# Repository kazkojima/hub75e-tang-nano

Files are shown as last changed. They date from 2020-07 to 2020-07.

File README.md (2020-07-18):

## HUB75E driver with Tang Nano FPGA and WiFi adaptor with M5ATOM

The driver part by Tang Nano for 64x64 LED panels with the HUB75E
interface is based on https://github.com/shinyblink/sled-fpga-hub75.

The WiFi part by M5ATOM is an esp-idf application. It receives RGB565
udp packet format of [LED master](https://github.com/spectrenoir06/LED_master)
and writes the frame data to FPGA with SPI.

The main SPI should assert CS, write 64x64(4096) RGB555 words and negate CS
with mode0. The HUB75E panel is divided to 2 64x32 planes and the SPI data
should be organized as

```
   word 0, word 2048, word 1, word 2049, ... , word 2047, word 4095
```

so as to get 2 words for both panels at the same time with one 32-bit data
from BRAM.

This driver does nothing to sync frame read/write from/to BRAM, the images
displayed on the top and bottom panels may be out of sync.

I use 16Mhz clock for the base clock to minimize the artifacts on my panel,
though there may be panels which can be ok with the higher clocks. SPI
requires the base clock which is at least x4 the SCLK, i.e. the maximal
SCLK is limited by 4Mhz for the 16Mhz base clock.

All sources are covered by ISC License, except src/hub75e.{sdc,cst} files
which are generated files by GOWIN IDE.

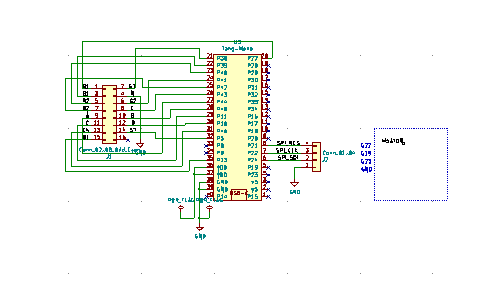
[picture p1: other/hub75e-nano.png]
simple schematic


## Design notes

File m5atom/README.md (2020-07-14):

## M5ATOM Matrix ESP-IDF sample

This is a sample application of M5ATOM Matrix. Recieve RGB565 format udp
packets from [LEDs master](https://github.com/spectrenoir06/LED_master)
amd writes the frame to HUB75E interface via SPI.

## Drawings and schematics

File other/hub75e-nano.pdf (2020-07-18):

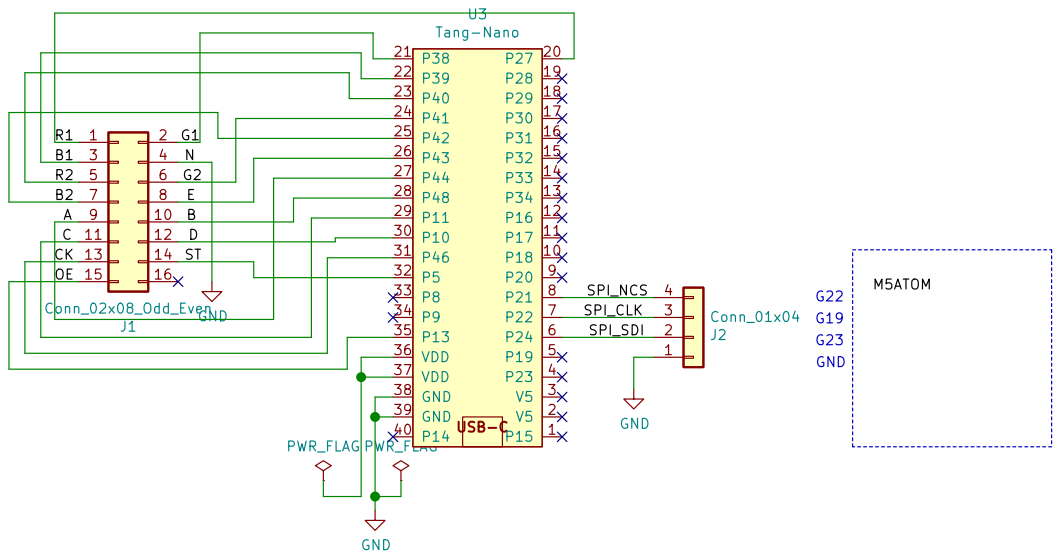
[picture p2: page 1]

11 | | 12 14
13

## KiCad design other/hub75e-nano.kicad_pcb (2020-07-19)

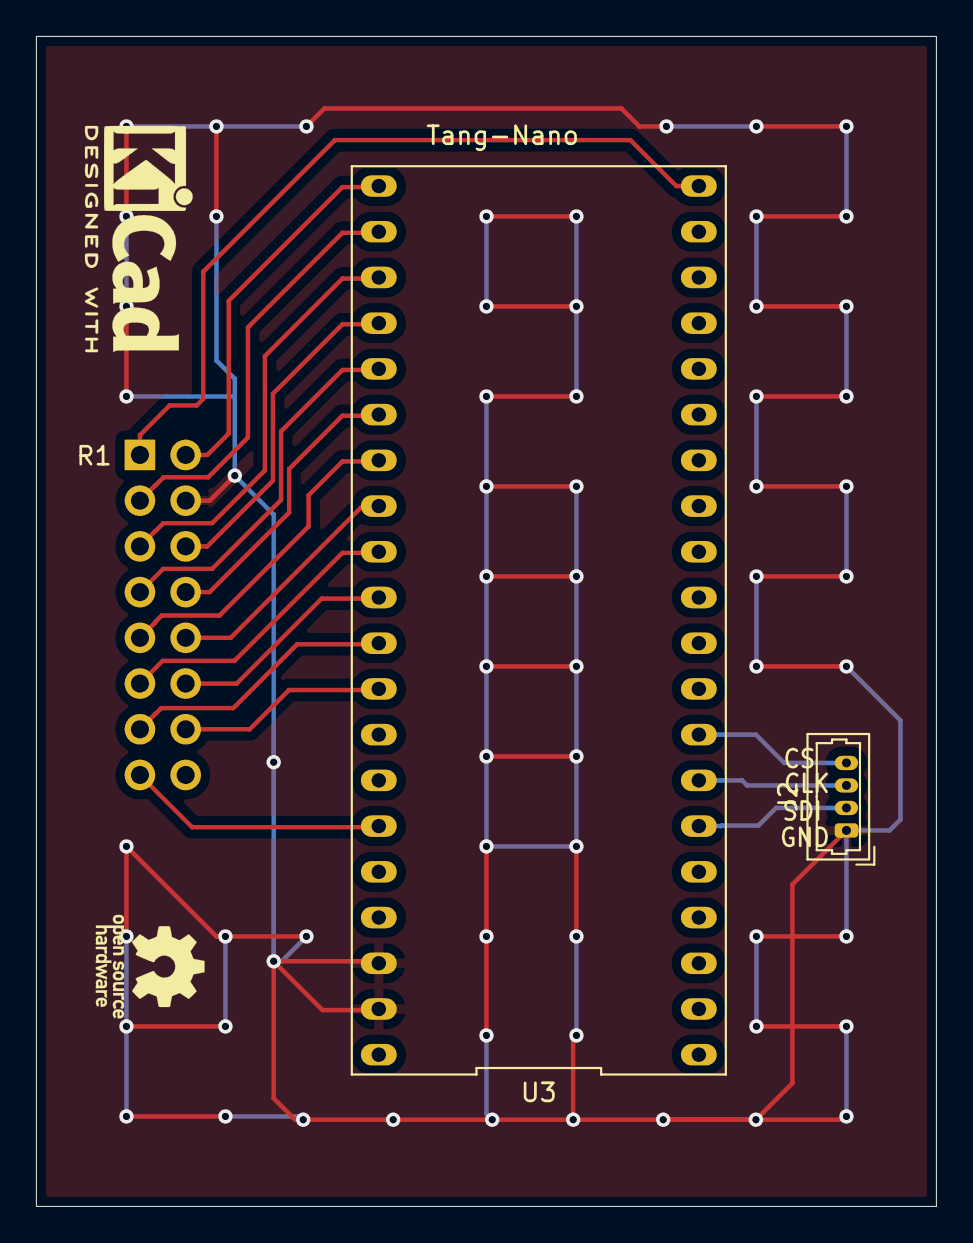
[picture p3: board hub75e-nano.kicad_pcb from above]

Board: 2 copper layers, 50.0 x 65.0 mm, 3 parts (1 on the bottom side), 19 nets.

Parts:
J1: Conn_02x08_Odd_Even; PinSocket_2x08_P2.54mm_Vertical
J2: Conn_01x04; Molex_PicoBlade_53047-0410_1x04_P1.25mm_Vertical
U3: Tang-Nano; DIP-40_700_ELL

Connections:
/A: J1.9, U3.27
/B: J1.10, U3.28
/B1: J1.3, U3.22
/B2: J1.7, U3.25
/C: J1.11, U3.29
/CK: J1.13, U3.31
/D: J1.12, U3.30
/E: J1.8, U3.26
/G1: J1.2, U3.21
/G2: J1.6, U3.24
/OE: J1.15, U3.35
/R1: J1.1, U3.20
/R2: J1.5, U3.23
/SPI_CLK: J2.3, U3.7
/SPI_NCS: J2.4, U3.8
/SPI_SDI: J2.2, U3.6
/ST: J1.14, U3.32
GND: J1.4, J2.1, U3.38, U3.39
unnamed: U3.36, U3.37

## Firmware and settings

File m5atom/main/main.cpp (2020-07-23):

/// -*- tab-width: 4; Mode: C++; c-basic-offset: 4; indent-tabs-mode: nil -*-

#include <cstdio>
#include <cstring>
#include <cstdlib>

#include "freertos/FreeRTOS.h"
#include "freertos/task.h"
#include "freertos/queue.h"
#include "freertos/event_groups.h"
#include "esp_system.h"
#include "esp_wifi.h"
#include "esp_event.h"
#include "esp_log.h"
#include "nvs_flash.h"
#include "driver/i2c.h"
#include "driver/spi_master.h"
#include "driver/gpio.h"
#include "sdkconfig.h"

#include "neopixel.h"

#include "lwip/err.h"
#include "lwip/sockets.h"
#include "lwip/sys.h"
/* FreeRTOS event group to signal when we are connected*/
static EventGroupHandle_t s_wifi_event_group;

/* The event group allows multiple bits for each event, but we only care about two events:
 * - we are connected to the AP with an IP
 * - we failed to connect after the maximum amount of retries */
#define WIFI_CONNECTED_BIT BIT0
#define WIFI_FAIL_BIT      BIT1

static const char *TAG = "wifi station";

static int s_retry_num = 0;

extern "C" void event_handler(void* arg, esp_event_base_t event_base,
                              int32_t event_id, void* event_data)
{
  if (event_base == WIFI_EVENT && event_id == WIFI_EVENT_STA_START) {
    esp_wifi_connect();
  } else if (event_base == WIFI_EVENT && event_id == WIFI_EVENT_STA_DISCONNECTED) {
    if (s_retry_num < CONFIG_WIFI_MAXIMUM_RETRY) {
      esp_wifi_connect();
      s_retry_num++;
      ESP_LOGI(TAG, "retry to connect to the AP");
    } else {
      xEventGroupSetBits(s_wifi_event_group, WIFI_FAIL_BIT);
    }
    ESP_LOGI(TAG,"connect to the AP fail");
  } else if (event_base == IP_EVENT && event_id == IP_EVENT_STA_GOT_IP) {
    ip_event_got_ip_t* event = (ip_event_got_ip_t*) event_data;
    ESP_LOGI(TAG, "got ip:%s",
	     ip4addr_ntoa(&event->ip_info.ip));
    s_retry_num = 0;
    xEventGroupSetBits(s_wifi_event_group, WIFI_CONNECTED_BIT);
  }
}

void wifi_init_sta()
{
  s_wifi_event_group = xEventGroupCreate();

  tcpip_adapter_init();

  ESP_ERROR_CHECK(esp_event_loop_create_default());

  wifi_init_config_t cfg = WIFI_INIT_CONFIG_DEFAULT();
  ESP_ERROR_CHECK(esp_wifi_init(&cfg));

  ESP_ERROR_CHECK(esp_event_handler_register(WIFI_EVENT, ESP_EVENT_ANY_ID, &event_handler, NULL));
  ESP_ERROR_CHECK(esp_event_handler_register(IP_EVENT, IP_EVENT_STA_GOT_IP, &event_handler, NULL));

  ESP_ERROR_CHECK(esp_wifi_set_mode(WIFI_MODE_STA) );
  wifi_config_t wifi_config;
  memset(&wifi_config, 0, sizeof(wifi_config));
  strcpy((char *)wifi_config.sta.ssid, CONFIG_WIFI_SSID);
  strcpy((char *)wifi_config.sta.password, CONFIG_WIFI_PASSWORD);
  wifi_config.sta.pmf_cfg.capable = true;
  wifi_config.sta.pmf_cfg.required = false;
  ESP_ERROR_CHECK(esp_wifi_set_config(ESP_IF_WIFI_STA, &wifi_config) );
  ESP_ERROR_CHECK(esp_wifi_start() );

  ESP_LOGI(TAG, "wifi_init_sta finished.");

  /* Waiting until either the connection is established (WIFI_CONNECTED_BIT) or connection failed for the maximum
   * number of re-tries (WIFI_FAIL_BIT). The bits are set by event_handler() (see above) */
  EventBits_t bits = xEventGroupWaitBits(s_wifi_event_group,
					 WIFI_CONNECTED_BIT | WIFI_FAIL_BIT,
					 pdFALSE,
					 pdFALSE,
					 portMAX_DELAY);

  /* xEventGroupWaitBits() returns the bits before the call returned, hence we can test which event actually
   * happened. */
  if (bits & WIFI_CONNECTED_BIT) {
    ESP_LOGI(TAG, "connected to ap SSID:%s password:%s",
	     CONFIG_WIFI_SSID, CONFIG_WIFI_PASSWORD);
  } else if (bits & WIFI_FAIL_BIT) {
    ESP_LOGI(TAG, "Failed to connect to SSID:%s, password:%s",
	     CONFIG_WIFI_SSID, CONFIG_WIFI_PASSWORD);
  } else {
    ESP_LOGE(TAG, "UNEXPECTED EVENT");
  }

  ESP_ERROR_CHECK(esp_event_handler_unregister(IP_EVENT, IP_EVENT_STA_GOT_IP, &event_handler));
  ESP_ERROR_CHECK(esp_event_handler_unregister(WIFI_EVENT, ESP_EVENT_ANY_ID, &event_handler));
  vEventGroupDelete(s_wifi_event_group);
}

// ATOM LED

#define I2C_MASTER_SCL_IO               (gpio_num_t)21
#define I2C_MASTER_SDA_IO               (gpio_num_t)25
#define I2C_MASTER_NUM                  (i2c_port_t)I2C_NUM_0
#define I2C_MASTER_TX_BUF_DISABLE       0
#define I2C_MASTER_RX_BUF_DISABLE       0
#define I2C_MASTER_FREQ_HZ              400000

#define I2C_PORT                        I2C_MASTER_NUM
#define WRITE_BIT                       I2C_MASTER_WRITE
#define READ_BIT                        I2C_MASTER_READ
#define ACK_CHECK_EN                    0x1
#define ACK_CHECK_DIS                   0x0
#define ACK_VAL                         (i2c_ack_type_t)0x0
#define NACK_VAL                        (i2c_ack_type_t)0x1

void _I2CInit(void)
{
    i2c_port_t i2c_master_port = I2C_MASTER_NUM;
    i2c_config_t conf;
    conf.mode = I2C_MODE_MASTER;
    conf.sda_io_num = I2C_MASTER_SDA_IO;
    conf.sda_pullup_en = GPIO_PULLUP_ENABLE;
    conf.scl_io_num = I2C_MASTER_SCL_IO;
    conf.scl_pullup_en = GPIO_PULLUP_ENABLE;
    conf.master.clk_speed = I2C_MASTER_FREQ_HZ;
    i2c_param_config(i2c_master_port, &conf);
    i2c_driver_install(i2c_master_port, conf.mode,
                       I2C_MASTER_RX_BUF_DISABLE, I2C_MASTER_TX_BUF_DISABLE,
                       0);
}

esp_err_t _I2CReadN(uint8_t addr, uint8_t reg, uint8_t *buf, size_t len)
{
    i2c_cmd_handle_t cmd = i2c_cmd_link_create();
    i2c_master_start(cmd);
    i2c_master_write_byte(cmd, (addr << 1)|WRITE_BIT,
			  ACK_CHECK_EN);
    i2c_master_write_byte(cmd, reg, ACK_CHECK_EN);
    i2c_master_stop(cmd);
    esp_err_t ret = i2c_master_cmd_begin(I2C_PORT, cmd, 1000/portTICK_RATE_MS);
    i2c_cmd_link_delete(cmd);
    if (ret != ESP_OK) {
        return ret;
    }
    cmd = i2c_cmd_link_create();
    i2c_master_start(cmd);
    i2c_master_write_byte(cmd, (addr << 1)|READ_BIT,
			  ACK_CHECK_EN);
    if (len > 1) {
        i2c_master_read(cmd, buf, len - 1, ACK_VAL);
    }
    i2c_master_read_byte(cmd, buf + len - 1, NACK_VAL);
    i2c_master_stop(cmd);
    ret = i2c_master_cmd_begin(I2C_PORT, cmd, 1000/portTICK_RATE_MS);
    i2c_cmd_link_delete(cmd);
    return ret;
}

esp_err_t _I2CWrite1(uint8_t addr, uint8_t reg, uint8_t val)
{
    uint8_t d = val;
    i2c_cmd_handle_t cmd = i2c_cmd_link_create();
    i2c_master_start(cmd);
    i2c_master_write_byte(cmd, (addr << 1)|WRITE_BIT,
			  ACK_CHECK_EN);
    i2c_master_write_byte(cmd, reg, ACK_CHECK_EN);
    i2c_master_write(cmd, &d, 1, ACK_CHECK_EN);
    i2c_master_stop(cmd);
    esp_err_t ret = i2c_master_cmd_begin(I2C_PORT, cmd, 1000/portTICK_RATE_MS);
    i2c_cmd_link_delete(cmd);
    return ret;
}

// Button GPIO
#define BUTTON_PIN GPIO_NUM_39

// NEOPIXEL
#define NEOPIXEL_PORT					GPIO_NUM_27
#if CONFIG_ATOM_MATRIX
#define NR_LED							25
#elif CONFIG_ATOM_LITE
#define NR_LED							1
#endif
#define NEOPIXEL_RMT_CHANNEL            RMT_CHANNEL_0

void led_task(void *arg)
{
    pixel_settings_t px;
    uint32_t pixels[NR_LED];
    int i;
    int rc;

    rc = neopixel_init(NEOPIXEL_PORT, NEOPIXEL_RMT_CHANNEL);
    printf("neopixel_init rc = %d", rc);
    vTaskDelay(1000 / portTICK_PERIOD_MS);

    for (i = 0; i < NR_LED; i++) {
        pixels[i] = 0;
    }
    px.pixels = (uint8_t *)pixels;
    px.pixel_count = NR_LED;
    strcpy(px.color_order, "GRB");

    memset(&px.timings, 0, sizeof(px.timings));
    px.timings.mark.level0 = 1;
    px.timings.space.level0 = 1;
    px.timings.mark.duration0 = 12;
    px.nbits = 24;
    px.timings.mark.duration1 = 14;
    px.timings.space.duration0 = 7;
    px.timings.space.duration1 = 16;
    px.timings.reset.duration0 = 600;
    px.timings.reset.duration1 = 600;

    px.brightness = 0x08;
    np_show(&px, NEOPIXEL_RMT_CHANNEL);

    int fact = 1;
    while (true) {
        vTaskDelay(10 / portTICK_PERIOD_MS);

        // tirangle wave
        for (int j = 0; j < NR_LED; j++) {
            np_set_pixel_rgbw(&px, j, i, i, i, 0);
        }
        np_show(&px, NEOPIXEL_RMT_CHANNEL);
        if (fact > 0) {
            i += 1;
        } else {
            i -= 1;
        }
        if (i == 255) {
            fact = -1;
        } else if ( i == 0 ) {
            fact = 1;
        }
    }
}

// For SPI connected HUB75E driver

#define PIN_NUM_MOSI GPIO_NUM_23
#define PIN_NUM_CLK  GPIO_NUM_19
#define PIN_NUM_CS   GPIO_NUM_22

spi_device_handle_t spi_led;

void spi_init(void)
{
    esp_err_t ret;
    spi_bus_config_t buscfg;
    memset(&buscfg, 0, sizeof(buscfg));
    buscfg.miso_io_num=-1;
    buscfg.mosi_io_num=PIN_NUM_MOSI;
    buscfg.sclk_io_num=PIN_NUM_CLK;
    buscfg.quadwp_io_num=-1;
    buscfg.quadhd_io_num=-1;
    buscfg.max_transfer_sz=0;

    spi_device_interface_config_t devcfg;
    memset(&devcfg, 0, sizeof(devcfg));
    devcfg.command_bits=0;
    devcfg.address_bits=0;
    devcfg.dummy_bits=0;
    devcfg.clock_speed_hz=4000000;	//Clock out at 4MHz
    devcfg.duty_cycle_pos=128;
    devcfg.mode=0;                  //SPI mode 0
    devcfg.cs_ena_posttrans=1;
    devcfg.spics_io_num=-1;         //no hardware CS pin
    devcfg.queue_size=1;
    devcfg.flags=0;

    ret=spi_bus_initialize(VSPI_HOST, &buscfg, 0);
    assert(ret==ESP_OK);
    //Attach the slave devices to the SPI bus
    ret=spi_bus_add_device(VSPI_HOST, &devcfg, &spi_led);
    assert(ret==ESP_OK);
}

esp_err_t led_writen(uint8_t *buf, size_t len)
{
  esp_err_t ret;
  static spi_transaction_t trans;
  memset(&trans, 0, sizeof(spi_transaction_t));
  trans.length = 8*len;
  trans.tx_buffer = buf;
  //printf("do transfer\n");
  ret = spi_device_transmit(spi_led, &trans);
  return ret;
}

uint8_t ledbuf[64*64*2];

#define LED_RGB_565 2
#define LED_RGB_565_UPDATE 3
#define MAX_RGBBUF_SIZE 1280
struct rpacket {
    uint8_t header;
    uint8_t count;
    uint16_t offset;
    uint16_t length;
    uint16_t rgbbuf[MAX_RGBBUF_SIZE/2];
} rpkt;

uint16_t RGB555(uint16_t rgb565)
{
    uint16_t h = (rgb565 & 0x1f) | ((rgb565 >> 1) & ~0x1f);
    return (h >> 8) | (h << 8);
}

void set_ledbuf(struct rpacket *p)
{
    //printf("pckt offset %d length %d\n", p->offset, p->length);
    for (int i = 0; i < p->length; i++) {
        int idx = p->offset + i;
        if (idx >= 2048) {
            idx &= (2048-1);
            ((uint16_t *)ledbuf)[idx << 1] = RGB555(p->rgbbuf[i]);
        } else {
            ((uint16_t *)ledbuf)[(idx << 1) + 1] = RGB555(p->rgbbuf[i]);
        }
    }
}

#define SPI_LENGTH (8*4)

void udp_task(void *arg)
{
  wifi_init_sta();

  struct sockaddr_in caddr;
  struct sockaddr_in saddr;
  int sock = socket(AF_INET, SOCK_DGRAM, 0);
  if (sock < 0) {
    printf("UDP socket can't be opened.\n");
    vTaskDelete(NULL);
  }

  saddr.sin_family = AF_INET;
  saddr.sin_addr.s_addr = htonl(INADDR_ANY);
  saddr.sin_port = htons(CONFIG_UDP_PORT);
  if (bind (sock, (struct sockaddr *)&saddr, sizeof(saddr)) < 0) {
    printf("Failed to bind UDP socket.\n");
    vTaskDelete(NULL);
  }

  while(true) {
    socklen_t clen;
    ssize_t n = recvfrom(sock, (char *)&rpkt, sizeof(rpkt), 0,
			 (struct sockaddr *)&caddr, &clen);
    if (n < 0) {
      printf("Failed to recv UDP socket.\n");
    }
    if (n < 6) {
      continue;
    }
    // handle packet header 0x02/0x03
    if (rpkt.header != LED_RGB_565 && rpkt.header != LED_RGB_565_UPDATE) {
      // ignore this packet
      printf("bad packet (size %d) start with %02x\n", n, rpkt.header);
      continue;
    }
    // TODO check count

    // Set ledbuf
    set_ledbuf(&rpkt);
    if (rpkt.header == LED_RGB_565_UPDATE) {
        //printf("end packet (idx %d)\n", rpkt.count);
        // end packet
        gpio_set_level(PIN_NUM_CS, 0);
        for (int i = 0; i < sizeof(ledbuf); i += SPI_LENGTH) {
            led_writen(&ledbuf[i], SPI_LENGTH);
        }
        gpio_set_level(PIN_NUM_CS, 1);
    } else {
        ;//printf("detect packet (count %d)\n", rpkt.count);
    }
  }
}

extern "C" void app_main()
{
    //Initialize NVS
    nvs_flash_init();

    gpio_reset_pin(PIN_NUM_CS);
    gpio_set_level(PIN_NUM_CS, 1);
    gpio_set_direction(PIN_NUM_CS, GPIO_MODE_OUTPUT);

    spi_init();

    memset(ledbuf, 0, sizeof(ledbuf));

    
    xTaskCreate(led_task, "led_task", 8192, NULL, 2, NULL);
    xTaskCreate(udp_task, "udp_task", 8192, NULL, 3, NULL);

    gpio_set_direction(BUTTON_PIN, GPIO_MODE_INPUT);
    while (true) {
        vTaskDelay(1000 / portTICK_PERIOD_MS);
    }
}

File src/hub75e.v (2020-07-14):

module hub75e_if (
		  input 	clk,
		  input 	resetn,
		  output [4:0] 	lines,
		  output 	hub_ck,
		  output	hub_st,
		  output reg	hub_oe,
		  output [10:0] ram_addr,
		  output reg 	frame_clk
);
   reg [10:0] 			   hub_addr;
   reg [4:0] 			   line;
   reg [1:0] 			   state = 0;
   assign ram_addr = hub_addr;
   assign hub_ck = clk & ~frame_clk;
   assign hub_st = clk & frame_clk;
   assign lines = hub_addr[10:6] - 1;

   always @(negedge clk) begin
      if (!resetn) begin
	 state <= 0;
	 hub_addr <= 0;
	 line <= 0;
	 frame_clk <= 0;
     hub_oe <= 0;
      end
      if (state == 0) begin
	 if (hub_addr[5:0] == 63) begin
	    frame_clk <= 1;
        hub_oe <= 1;
	    state <= 1;
	 end else begin
	    hub_addr <= hub_addr + 1;
	    frame_clk <= 0;
	    state <= 0;
	 end
      end
      else if (state == 1) begin
	 state <= 2;
      end
      else if (state == 2) begin
	 frame_clk <= 0;
	 hub_addr <= hub_addr + 1;
	 state <= 3;
      end
      else if (state == 3) begin
     hub_oe <= 0;
	 state <= 0;
      end
   end // always @ (negedge pin_clk)

endmodule // hub75e_if

module pixram (
	       input wire 	 clk,
	       input wire 	 read,
	       input wire 	 write,
	       input wire [10:0] raddr,
	       input wire [10:0] waddr,
	       output reg [31:0] data_out,
	       input wire [31:0] data_in
);

   reg [31:0] 			 mem[0:2048-1];

   always @(posedge clk) begin
      if (write) begin
         mem[waddr] <= data_in;
      end
      if (read) begin
	 data_out <= mem[raddr];
      end
   end // always @ (posedge clk)

endmodule // pixram

module hub75e (
	       input wire 	 CLK_IN,
	       input wire 	 USER_KEY,
	       output wire   led_r,
           output wire   led_g,
           output wire   led_b,
	       output wire 	 hub_R1,
	       output wire 	 hub_G1,
	       output wire 	 hub_B1,
	       output wire 	 hub_R2,
	       output wire 	 hub_G2,
	       output wire 	 hub_B2,
	       output wire 	 hub_E,
	       output wire 	 hub_A,
	       output wire 	 hub_B,
	       output wire 	 hub_C,
	       output wire 	 hub_D,
	       output wire 	 hub_CK,
	       output wire 	 hub_ST,
	       output wire 	 hub_OE,
//	       output wire 	 dbg_0,
//	       output wire 	 dbg_1,
	       input wire 	 spi_clk,
 	       input wire 	 spi_mosi,
	       input wire 	 spi_cs
);

   // Power-on and user reset
   reg [5:0] 			 reset_cnt = 0;
   wire 			 presetn = &reset_cnt;
   reg               uresetn = 0;
   wire              resetn = presetn & uresetn;

   always @(posedge CLK_IN) begin
      reset_cnt <= reset_cnt + !presetn;
      uresetn <= USER_KEY;
   end

   wire   clock;
   //wire   extlock;
   //pll pll0(CLK_IN, 1'b0, extlock, clock);
   assign clock = CLK_IN;

   wire [31:0] ram_wdata;
   wire [10:0] ram_raddr;
   wire [15:0] ram_rdata1;
   wire [15:0] ram_rdata2;

   wire frame_clk;

   // Setup SPI and data transfers.
   wire spi_firstword;
   wire spi_done;
   wire spi_idle;
   reg [10:0] spi_word_count = 0;
   reg 	      first_cycle_done = 0;

   spi_satellite spi(clock, resetn, spi_clk, spi_mosi, spi_cs,
		 ram_wdata, spi_firstword, spi_done, spi_idle);

   always @(posedge clock) begin
       if (!resetn) begin
	 spi_word_count <= 0;
	 first_cycle_done <= 0;
      end

      if (spi_firstword || spi_idle) begin
         spi_word_count <= 0;
      end

      if (spi_done) begin
         spi_word_count <= spi_word_count + 1;
 	 if (&spi_word_count) begin
	    first_cycle_done <= 1;
	 end
      end

   end // always @ (posedge clock)

   // Pixel 2-port ram
   pixram pram(clock, 1'b1, spi_done, ram_raddr, spi_word_count,
	      {ram_rdata2, ram_rdata1}, ram_wdata);

   // Generate IF signals
   wire [4:0] lines;
   assign { hub_E, hub_D, hub_C, hub_B, hub_A } = lines;
 
   hub75e_if hubif(clock, resetn, lines, hub_CK, hub_ST, hub_OE, ram_raddr, frame_clk);

   // 5 bit PWM.
   reg [9:0] frame_count;
   always @(posedge frame_clk) begin
      if (!resetn) begin
	 frame_count <= 0;
      end
      else begin
	 frame_count <= frame_count + 1;
      end
   end

   // Enable display
   wire enable;
   assign       enable = first_cycle_done;

   assign hub_R1 = (ram_rdata1[14:10] > frame_count[9:5]) & enable;
   assign hub_G1 = (ram_rdata1[9:5] > frame_count[9:5]) & enable;
   assign hub_B1 = (ram_rdata1[4:0] > frame_count[9:5]) & enable;
   assign hub_R2 = (ram_rdata2[14:10] > frame_count[9:5]) & enable;
   assign hub_G2 = (ram_rdata2[9:5] > frame_count[9:5]) & enable;
   assign hub_B2 = (ram_rdata2[4:0] > frame_count[9:5]) & enable;


   assign led_r = 1'b1;
   assign led_b = 1'b1;
   assign led_g = ~spi_cs;

endmodule // hub75e

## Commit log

2020-07-18 Add an example schematic.
    [hub75e-nano.kicad_pcb]
2020-07-19 Drop pcb temporarily.
    [hub75e-nano.kicad_pcb]
2020-07-19 Add a revised pcb layout.
    [hub75e-nano.kicad_pcb]
